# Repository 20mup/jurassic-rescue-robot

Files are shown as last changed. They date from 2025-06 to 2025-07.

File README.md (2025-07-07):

# 🦖 Jurassic Rescue Robot

A semi-autonomous rescue robot developed for the **MREN 303: Mechatronics Design** course at Queen’s University. Designed to traverse a gameboard, press a gate-opening button autonomously, and manually retrieve a "Ken" doll while clearing the "dinosaur" figures under strict hardware constraints.

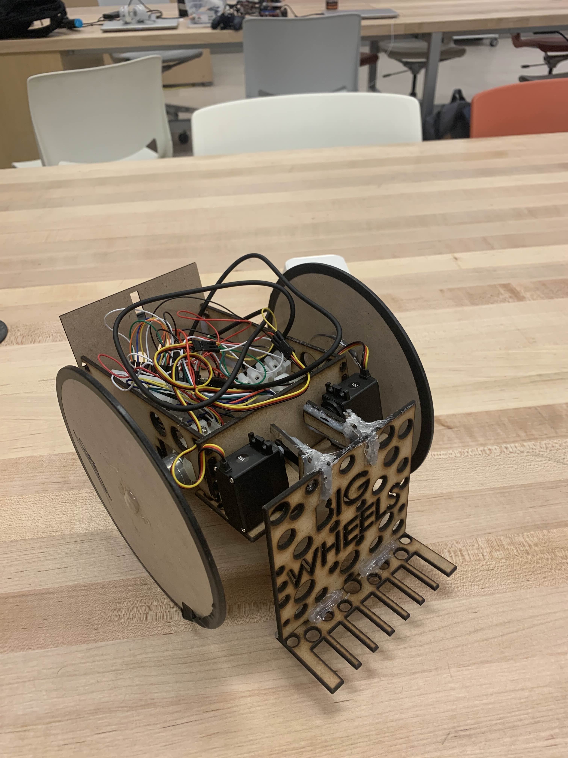
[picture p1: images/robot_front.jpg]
Robot Front View


---

## 🏆 Awards

> 🥇 **People’s Choice Award** – Voted best design and execution by peers and faculty.

---

## 📸 Gallery

| Front | Side | Back |
|---|---|---|
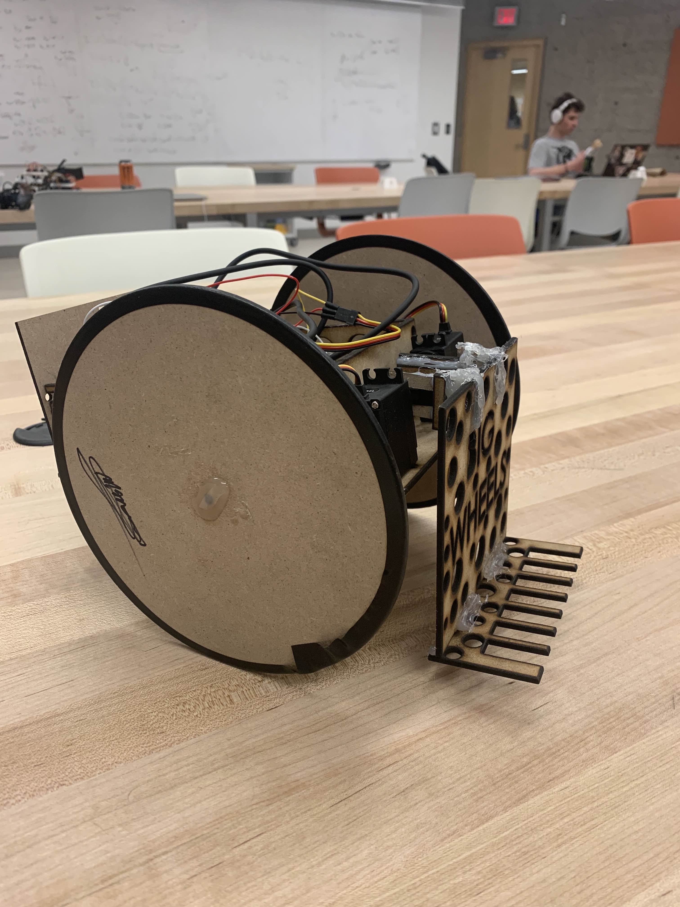
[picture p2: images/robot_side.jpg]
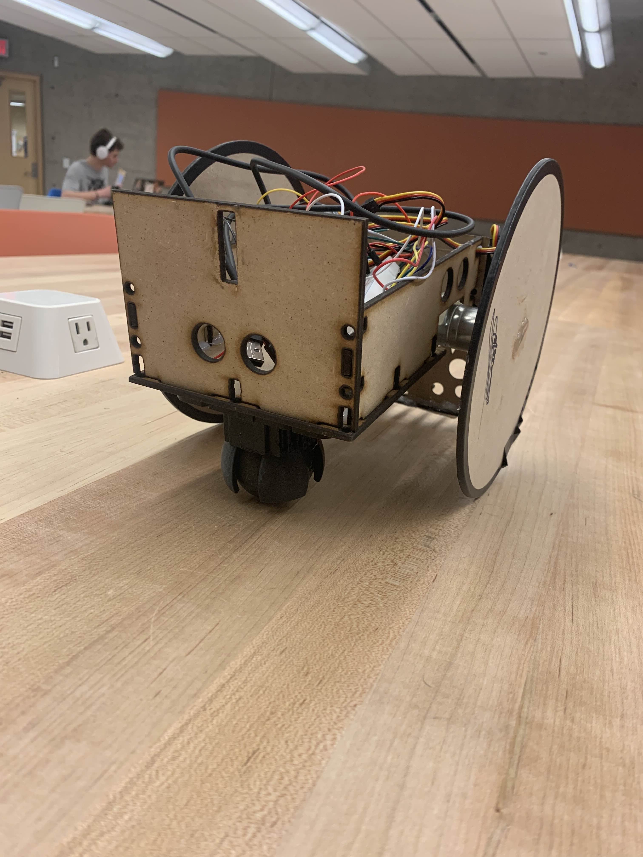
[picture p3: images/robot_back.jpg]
|  |  |  |

| Award | Circuit | Gameboard |
|---|---|---|
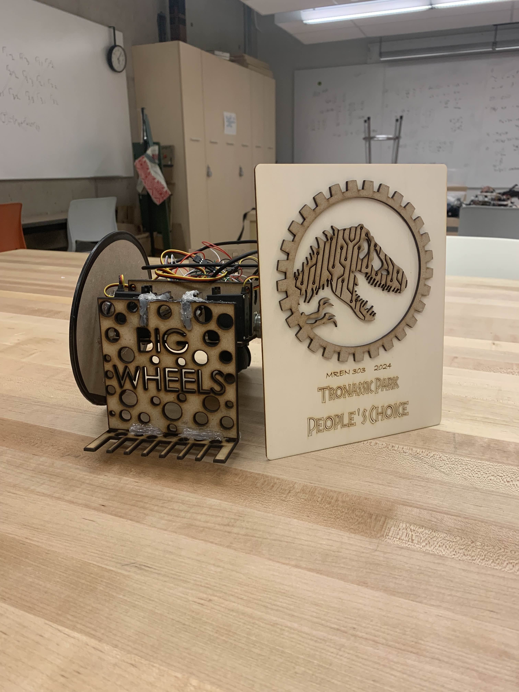
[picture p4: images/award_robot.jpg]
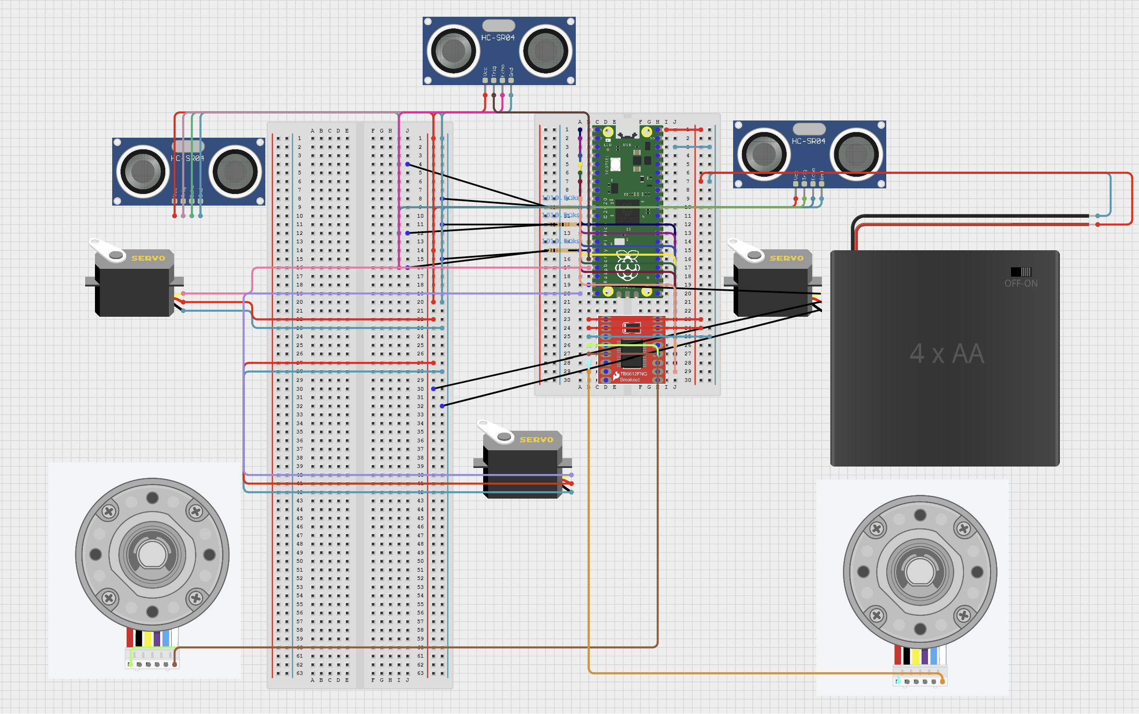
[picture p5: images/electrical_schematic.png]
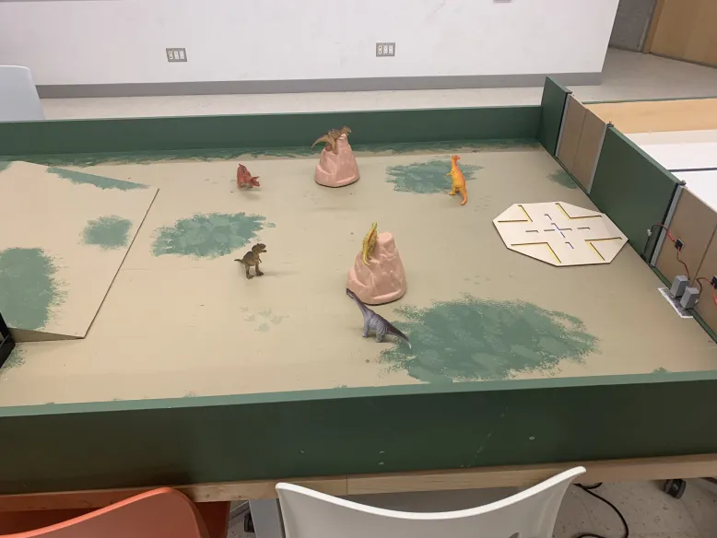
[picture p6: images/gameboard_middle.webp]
|  |  |  |

---

## 🚀 Project Overview

Built for Queen’s University’s **Tronassic Park Competition**, this robot combined autonomous and manual control to complete a two-phase mission:
- **Phase 1:** Autonomously press a button to open a gate.
- **Phase 2:** Switch to joystick control to retrieve a toy figure from a pit.

---

## 🧩 Problem / 💡 Solution

**Problem:** Navigate an uneven gameboard, press a button accurately, and retrieve an object — all using only 3 servo motors and custom electronics.  
**Solution:** A compact, dual-mode robot using ultrasonic alignment and DC motor encoders, with a front clamp to lift the target figure like a forklift.

---

## ✨ Key Features

- Autonomous navigation using ultrasonic sensors
- Manual control via joystick (Arduino + Pico W)
- Closed-loop motor feedback with DC encoders
- Custom 3D-printed chassis and laser-cut wheels
- Integrated power management (voltage dividers)
- Emergency override via controller

---

## 💻 Tech Stack

| Area | Tools / Tech |
|---|---|
| Microcontroller | Raspberry Pi Pico W, Arduino |
| Programming | MicroPython, Arduino C++ |
| CAD & Fabrication | SolidWorks, laser cutting, 3D printing |
| Communication | USB Serial, Joystick |

---

## 📁 Project Structure

```bash
JurassicRescueRobot/
├── code/                   # MicroPython + Arduino scripts
├── design/                 # CAD files (.SLDPRT, .STL, .DXF)
├── images/                 # Robot photos & schematics
├── docs/                   # Engineering case study & final report
└── README.md
```

---

## 👥 Team

- **Mousa Pirzada** – Lead Programmer: Pico W scripting, encoder feedback, integration.
- **Kaitlyn Johnston** – Electrical + Mechanical: Circuit design, CAD, fabrication.

---

## 📖 Learn More

- [📂 CAD Files & Build Details](https://github.com/20mup/JurassicRescueRobot/tree/main/design)
- [📄 Engineering Case Study](docs/jurassic-rescue-case-study.md)

---

> _Built with gears, wires, and the spirit of Jurassic Park._ 🦕

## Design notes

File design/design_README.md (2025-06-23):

# 🧩 Design Files — Jurassic Rescue Robot

This folder contains all mechanical design files used for laser cutting, 3D printing, and assembling the robot chassis and modules.

---

## 📐 Files Overview

### 🖨️ 3D Printing
- `Ball_Caster.stl`  
  → 3D model of the rear omni-directional caster. Positioned at the rear center of the chassis to support two-wheel drive turning.

---

### 🧱 SolidWorks CAD Parts (`.SLDPRT`)
- `Front.SLDPRT`  
  → Front chassis wall for structural support and mounting  
- `back.SLDPRT`  
  → Rear panel of the chassis  
- `base.SLDPRT`  
  → Bottom panel of the robot where all components were mounted  
- `sides.SLDPRT`  
  → Side walls, included for structure and possible mounting of sensors or decorations

> All parts were designed with tight tolerances for laser cutting and easy alignment.

---

### ✂️ Laser Cutting
- `WheelWithDimensions.dxf`  
  → Cut-ready DXF file for the robot’s wheel design. Includes dimensioning to ensure fit on the motor shaft and smooth rotation. Final version fixed tolerance issues seen in cardboard prototype.

---

## 🛠️ Assembly Notes

- All chassis panels were laser cut from wood/acrylic sheets
- Ball caster was 3D printed and press-fitted into the chassis
- Fitment tolerances were fine-tuned after testing in earlier rounds
- Final design minimized unnecessary weight and maximized stability for both manual and autonomous modes

---

## 🧪 Design Iteration Summary

- 📦 Round 1: Initial designs built with cardboard for fit testing  
- ✏️ Round 2–3: CAD models refined using SolidWorks  
- 🖨️ Round 4–5: Final parts laser cut or 3D printed and tested on the gameboard

---

## 👨‍💻 Contributors

- Mousa Pirzada — CAD Design + Fitment Testing  
- Kaitlyn Johnston — Laser Cut Prep + Fabrication

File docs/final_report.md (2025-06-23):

# 📘 Final Report — Jurassic Rescue Robot

**Course**: MREN 303 — Mechatronics and Robotics Design  
**Team**: Mousa Pirzada & Kaitlyn Johnston
**Award**: 🏆 People's Choice Award – Tronassic Park Robotics Challenge (2024)

---

## 🧠 Project Overview

This project challenged teams to build a robot for a Jurassic Park-themed gameboard. The robot's main tasks:
- Autonomously press a button to open a gate
- Manually rescue a doll (Ken) and deliver it to the helipad
- Bonus: corral dinosaur figures into a cage

Our final robot featured a dual mechanism: a **plow** for scooping and a **vertical clamp** for secure object retrieval, optimized for both speed and precision.

---

## 🔁 Design Round Reflections

### 🔹 Round 1: Concept Selection & Risk Assessment
- Brainstormed 5 mechanisms: plow, horizontal claw, frying pan, crane claw, and plow + vertical clamp
- Selected **Plow + Vertical Clamp** for versatility and simplicity
- Created a detailed FRDPARRC table and safety plan
- Prototyped designs using cardboard and began safety assessments

---

### 🔹 Round 2: Subsystem Development
- Learned to interface with motor drivers, servos, and ultrasonic sensors
- Measured all gameboard components and Ken
- Developed CAD for claw and chassis
- Built test circuits and began 3D printing wheels and laser cutting parts
- Identified tolerances and weaknesses in early prototypes

---

### 🔹 Round 3: Integration Begins
- Created full electrical schematic + power budget
- Wired encoders and developed PID motor control
- Combined all control code modules
- Integrated joystick/gamepad for manual control
- Assembled first physical robot with working electronics

---

### 🔹 Round 4: Autonomous Mode + Chassis Iteration
- Built new laser-cut + 3D printed chassis with better part tolerances
- Integrated all sensors and battery monitoring
- Switched between manual and autonomous modes using joystick control
- Tested robot on real gameboard; practiced navigation
- Refined claw design for reliable grip

---

### 🔹 Round 5: Final Testing & Competition Prep
- Implemented autonomous mode logic using ultrasonic sensors
- Merged all final code into single working build
- Final chassis iteration completed with tight motor fits
- Focused on closed-loop feedback performance and autonomous consistency
- Developed presentation and uploaded files for cutting

---

## 📊 Key Takeaways

- Learned how to use **Raspberry Pi Pico**, PWM, encoders, PID control, and servo logic
- Practiced **rapid iteration**, from cardboard to final laser/3D printed modules
- Used **Scrum** and weekly retrospectives to adjust goals, handle setbacks, and improve team dynamics
- Applied **sustainable design** principles by minimizing materials and optimizing energy use
- Balanced **precision + simplicity** under motor, size, and component constraints

---

## 💬 Team Reflections

- Team communication was consistent but could benefit from more mid-week meetings
- We grew stronger in emphasizing high standards, especially near the end
- Our confidence improved through troubleshooting and iteration
- Key lesson: always build in slack time for 3D printing, testing, and fallback planning

---

## 📎 Supporting Files

- 📐 Laser cut drawings (.DXF)
- 🧠 Control code (MicroPython)
- 🖼️ Photos: final robot, cardboard prototypes, award
- 🗂️ CAD files (SolidWorks)

---

## 🫂 Acknowledgements

Thanks to our instructors, lab staff, and peers who provided feedback and help throughout. This project was a powerful hands-on experience in robotics and teamwork.

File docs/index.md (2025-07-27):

# 🦖 Jurassic Rescue Robot — Case Study

> **A semester-long, fully custom robotics build for Queen’s University's MREN 303 design course.**  
> From concept to competition, this case study covers the technical process, design pivots, personal challenges, and final results.

---

## 🎯 Project Context

This project was the central component of **MREN 303: Mechatronics Design** at Queen’s University, a course focused on developing technical design skills through hands-on team projects. The in-class theory was minimal — most of the learning occurred during the development of a functional, competition-ready robot.

Our challenge:  
Design a **semi-autonomous robot** capable of navigating a Jurassic Park-themed board, pressing a gate-opening button autonomously, and retrieving a "dinosaur" figurine manually — all under strict mechanical, electrical, and coding constraints.

---

## 🧠 Initial Strategy

We started with the idea of a **ramp-plus-clamp** rescue mechanism. The concept was to guide the robot onto a sloped ramp, align with the object, and use a servo-powered claw to lift it.

However, this design quickly introduced problems:
- Too many degrees of freedom for the servos
- Increased instability due to shifting weight
- Complex alignment during pickup

After evaluating the trade-offs, we pivoted to a **forklift-style ramp**: a flat platform that could wedge under the object and lift it vertically — fewer moving parts, more reliable.

---

## 🛠️ My Role

As the **lead programmer**, I handled:
- **Raspberry Pi Pico W scripting**
- **Encoder integration and closed-loop motor feedback**
- **Autonomous navigation using ultrasonic sensors**
- **Manual joystick control tuning**
- **Electrical debugging and system integration**

I also participated in weekly Scrum planning, task breakdowns, and integration sessions with my teammate Kaitlyn.

---

## ⚠️ Final Week Setback

Two weeks before our final presentation and test drive, **my laptop’s hard drive failed**. I lost everything — code, notes, CAD references. With the final milestone fast approaching, I had no choice but to **rebuild my entire contribution from scratch**.

For two weeks, I worked non-stop:
- Rewriting all control logic from memory
- Re-integrating encoder feedback and motor control
- Running late-night hardware tests
- Debugging under pressure with no time to spare

Despite this major setback, we managed to finish and deliver the project on time — fully functional and ready for demo day.

---

## 📏 Constraints & Challenges

- **3 servo motor limit**
- **Raspberry Pi Pico W + Arduino hybrid**
- No pre-made chassis or wheels — all laser cut or 3D printed
- Physical button pressing required precision
- No external debugging tools beyond onboard prints

---

## 🧪 Testing Process

Testing was iterative and often frustrating:
- Ultrasonic sensor alignment required ideal angle calibration
- Closed-loop motor control needed constant PID retuning
- Button pressing demanded perfect perpendicular alignment
- Battery fluctuations affected consistency

We learned the importance of **physical tolerances**, **debounce logic**, and real-world testing beyond simulations.

---

## 🏁 Results

The robot successfully:
- Navigated the board autonomously to press the gate button
- Transitioned into manual mode for precision pickup
- Completed the full task sequence within the competition time

We were honored to win the:

> 🥇 **People’s Choice Award**  
> _Voted best robot design and execution by peers and faculty._

---

## 🧠 Takeaways

- Don’t overcomplicate early designs — iterate based on simplicity first
- CAD precision is just as important as code
- Documentation + backups are life-saving
- Clear division of roles made collaboration smooth
- Real innovation happens under constraints

---

## 👥 Team Members

- **Mousa Pirzada** — Lead Programming, System Integration, Motor Control
- **Kaitlyn Johnston** — CAD Design, Circuit Assembly, Fabrication

---

## 📎 Related Links

- [🔗 GitHub Repository](https://github.com/20mup/Jurassic-Rescue-Robot)
- [📂 CAD & Files](https://github.com/20mup/Jurassic-Rescue-Robot/design)
- [🏆 View the Main Portfolio Page](/projects/jurassic-rescue-robot)

---

> _Built with gears, wires, and the spirit of Jurassic Park._ 🦕

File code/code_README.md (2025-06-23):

# 🧠 Code Overview — Jurassic Rescue Robot

This folder contains the core codebase for our autonomous + manual control robot built with the Raspberry Pi Pico.

---

## 📂 Files

### `pico_main_control.ino`
- ⚙️ Arduino-style program uploaded to the Raspberry Pi Pico
- Receives joystick commands via WiFi (UDP)
- Controls:
  - Motors (via H-bridge)
  - Servos for claw/lifting mechanism
  - Ultrasonic sensor for autonomous navigation
  - Battery monitoring
- Includes logic for closed-loop feedback using motor encoders + PID control

---

### `gamepad_input_udp.py`
- 🕹️ Python script that runs on the host PC
- Reads gamepad input using the `inputs` package
- Sends encoded UDP packets to the robot’s IP address
- Supports:
  - Joystick X/Y axes
  - All buttons and triggers
  - Mode switching (manual vs autonomous)

> 🔧 Ensure your gamepad is in **XInput mode** and your PC is on the same WiFi network as the Pico.

---

## 🛠️ Setup Notes

- The Pico and the host machine must be connected to the **same network**
- The IP address in `gamepad_input_udp.py` must match the Pico’s assigned address
- Use `Thonny` or Arduino IDE to upload `.ino` code to the Pico
- Install Python dependencies:
  ```bash
  pip install inputs
  ```

---

## 🔄 Data Flow

```
Gamepad → PC (Python) → UDP → Raspberry Pi Pico → Motors / Servos / Sensors
```

---

## 📎 Dependencies

- Python 3.x
- [`inputs`](https://pypi.org/project/inputs/) (for reading gamepad input)
- Arduino/Thonny IDE for Pico code upload

---

## 👨‍💻 Authors

- Mousa Pirzada — Python + Embedded Logic
- Kaitlyn — Electronics + Hardware Integration

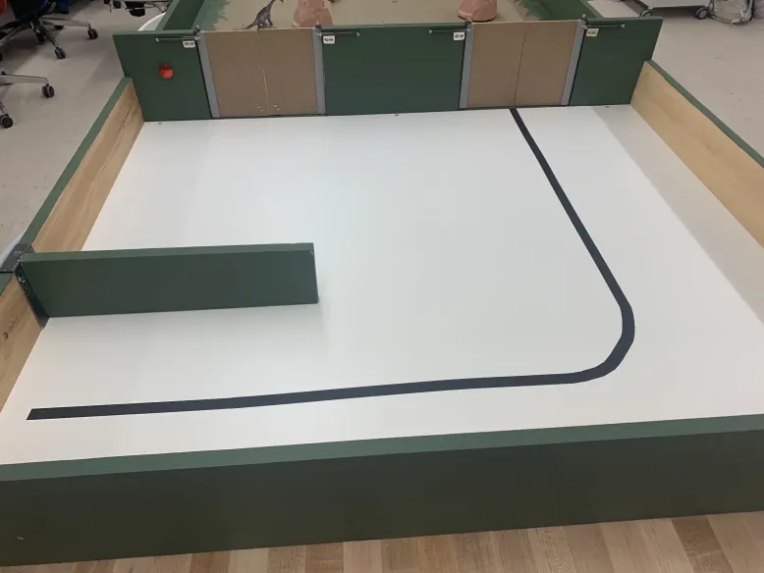
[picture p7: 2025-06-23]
images/gameboard_start.webp

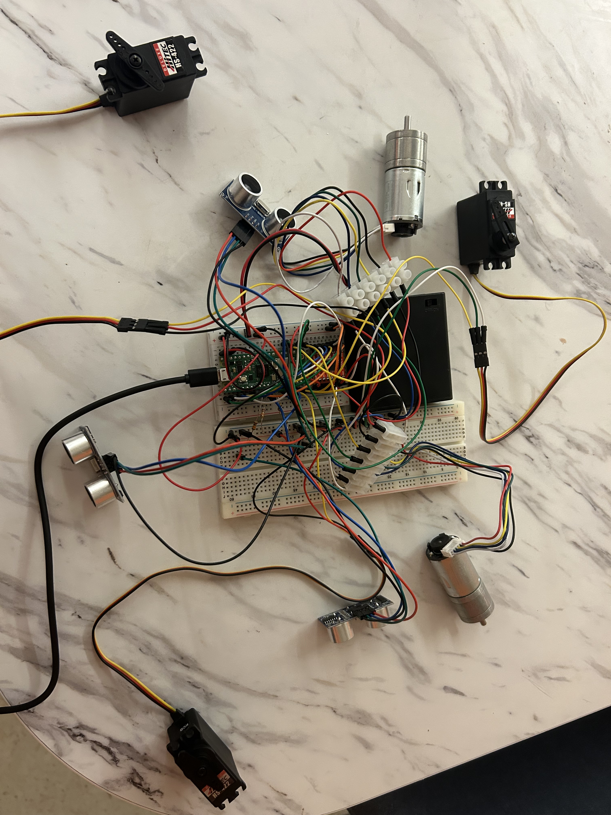
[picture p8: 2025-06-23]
images/Electrical_Circuit.jpg

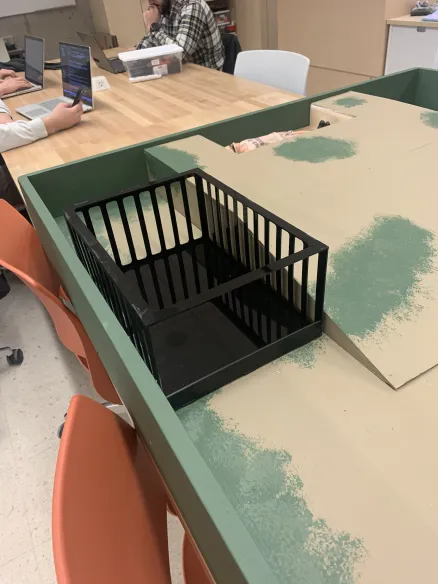
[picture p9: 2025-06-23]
images/gameboard_end.webp

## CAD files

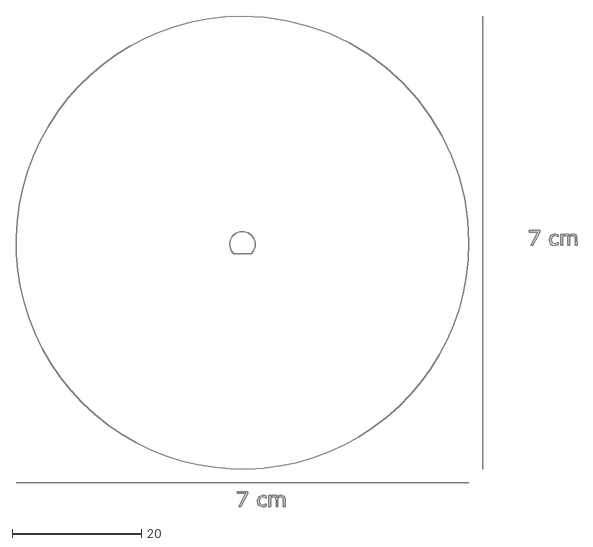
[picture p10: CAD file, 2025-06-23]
design/WheelWithDimensions.dxf
86.7 x 75.8

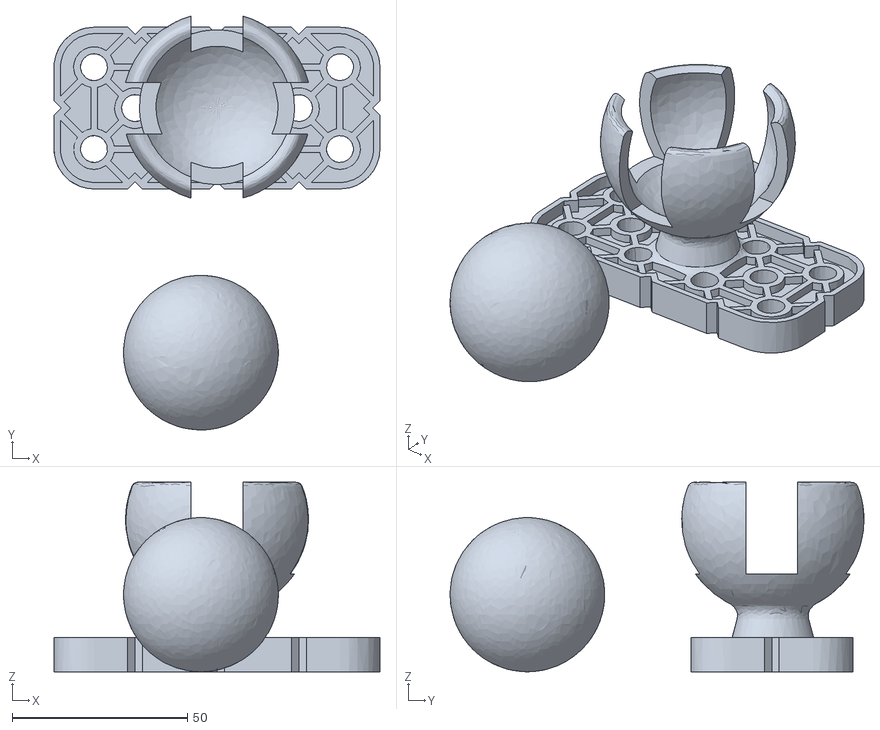
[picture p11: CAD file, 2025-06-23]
design/Ball_Caster.stl
93.0 x 118.1 x 54.1

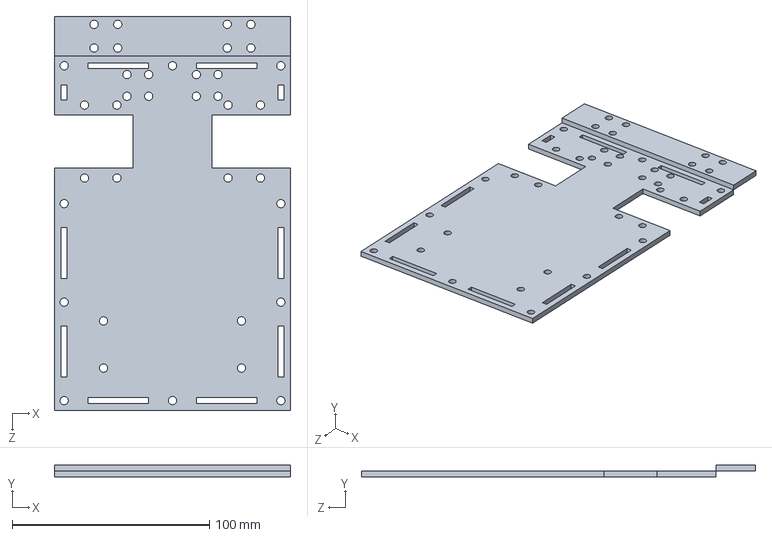
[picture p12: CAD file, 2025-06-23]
design/base.SLDPRT
120.0 x 6.00 x 200.0 mm

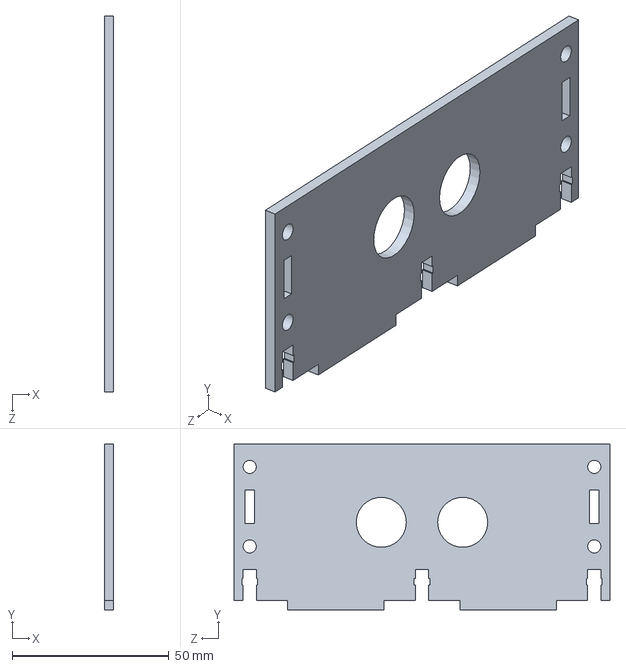
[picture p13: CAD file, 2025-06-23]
design/Front.SLDPRT
3.00 x 53.0 x 120.0 mm

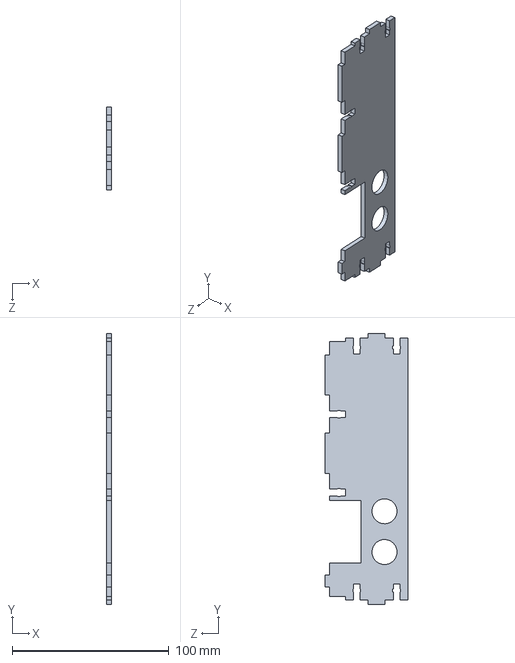
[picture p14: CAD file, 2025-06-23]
design/sides.SLDPRT
3.00 x 173.0 x 53.0 mm

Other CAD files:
design/back.SLDPRT

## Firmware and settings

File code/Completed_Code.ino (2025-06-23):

// MREN 303 Pico W Wifi Gamepad Read
// Written For MREN 303 

#include <WiFi.h>
#include <WiFiUdp.h>
#include <Servo.h>
#include <Arduino.h>

Servo myservo; 
Servo myservo2; 
Servo myservo3; 



#ifndef STASSID
#define STASSID "MREN303_wifi"
#define STAPSK "MREN@303p1"
#endif

unsigned int localPort = 8888;  // local port to listen on

// buffers for receiving and sending data
char packetBuffer[UDP_TX_PACKET_MAX_SIZE + 1];  // buffer to hold incoming packet,
char ReplyBuffer[22] = "acknowledged\r\n";        // a string to send back
// char Arrays to match commands from gamepad 
char stringA[17] =    "A Button Press";
char stringB[17] =    "B Button Press";
char stringY[17] =    "Y Button Press";
char stringX[17] =    "X Button Press";
char stringLB[17] =   "LB Button Press";
char stringRB[17] =   "RB Button Press";
char stringLS[17] =   "L Stick Press";
char stringRS[17] =   "R Stick Press";
char stringBack[17]=  "Back Press";
char stringStart[17]= "Start Press";
char stringUp[17] =   "Up Dpad Press";
char stringDown[17] = "Down Dpad Press";
char stringLeft[17] = "Left Dpad Press";
char stringRight[17]= "Right Dpad Press";
char stringLX[17] =   "L Stick X Value ";
char stringLY[17] =   "L Stick Y Value ";
char stringRX[17] =   "R Stick X Value ";
char stringRY[17] =   "R Stick Y Value ";
char stringLT[17] =   "L Trigger Value ";
char stringRT[17] =   "R Trigger Value ";

int valueLx = 0;
int valueLy = 0;
int valueRx = 0;
int valueRy = 0;
int valueLt = 0;
int valueRt = 0; 
int batteryLevel = 0;
int threshold = 100;
int threshold2 = -100;


bool ledOn = false;
bool pollBattery = false;
bool LeftMotorOn = false;
bool RightMotorOn = false;
bool LeftMotorOff = false;
bool RightMotorOff = false;
bool LeftMotorBack = false;
bool RightMotorBack = false;

//game modes
const int IDLE_MODE = 0;
const int AUTO_MODE = 1;
const int MANUAL_MODE = 2;
int current_mode = IDLE_MODE; // Variable to store the current mode. Starts in idle mode

unsigned long startTime = 0;  // Variable to store the start time
unsigned long currentTime = 0; // Variable to store the current time

WiFiUDP Udp;

// Define motor driver pins according to your hookup
const int PWMA = 19; // PWM control for motor speed, connect to PWM-enabled pin on Pico
const int AIN1 = 17; // Direction pin 1 for motor A, connect to a GPIO on Pico
const int AIN2 = 18; // Direction pin 2 for motor A, connect to a GPIO on Pico
const int STBY = 16; // Standby pin, connect to a GPIO on Pico
const int PWMA2 = 22; // PWM control for motor speed, connect to PWM-enabled pin on Pico
const int AIN12 = 20; // Direction pin 1 for motor A, connect to a GPIO on Pico
const int AIN22 = 21; // Direction pin 2 for motor A, connect to a GPIO on Pico
int counter = 0;

// defines pins numbers
const int trigPin = 3;
const int echoPin = 2;
const int trigPin1 = 1;
const int echoPin1 = 0;
const int trigPin2 = 5;
const int echoPin2 = 4;

// defines variables
long duration;
int distance;
long duration1;
int distance1;
long duration2;
int distance2;



void setup() { //This handles network function and runs on core 1
  Serial.begin(115200);
  WiFi.begin(STASSID, STAPSK);
  while (WiFi.status() != WL_CONNECTED) {
    Serial.print('.');
    delay(500);
  }
  Serial.print("Connected! IP address: ");
  Serial.println(WiFi.localIP());
  Serial.printf("UDP server on port %d\n", localPort);
  Udp.begin(localPort);

}
void setup1(){ //This handles all inputs and outputs and runs on core 2
  
  pinMode(LED_BUILTIN, OUTPUT);
  digitalWrite(LED_BUILTIN,0);
  myservo.attach(15);
  myservo2.attach(14);
  myservo3.attach(13);
  analogReadResolution(12); // 12 bit resolution = 0 - 4096 (2^12)

    // Set motor driver pins as outputs
  pinMode(PWMA, OUTPUT);
  pinMode(AIN1, OUTPUT);
  pinMode(AIN2, OUTPUT);
  pinMode(STBY, OUTPUT);
  pinMode(PWMA2, OUTPUT);
  pinMode(AIN12, OUTPUT);
  pinMode(AIN22, OUTPUT);

  pinMode(trigPin, OUTPUT); // Sets the trigPin as an Output
  pinMode(echoPin, INPUT); // Sets the echoPin as an Input
  pinMode(trigPin1, OUTPUT); // Sets the trigPin as an Output
  pinMode(echoPin1, INPUT); // Sets the echoPin as an Input
  pinMode(trigPin2, OUTPUT); // Sets the trigPin as an Output
  pinMode(echoPin2, INPUT); // Sets the echoPin as an Input
  
  // Pull standby pin high to enable the motor driver
  digitalWrite(STBY, HIGH);

}

void loop() { //This loop executes on Core 1 of the Pico, handles networking and recieves commands
  // if there's data available, read a packet
  int packetSize = Udp.parsePacket();
  if (packetSize) {
    Serial.printf("Received packet of size %d from %s:%d\n    (to %s:%d)\n", packetSize, Udp.remoteIP().toString().c_str(), Udp.remotePort(), Udp.destinationIP().toString().c_str(), Udp.localPort());

    // read the packet into packetBufffer
    int n = Udp.read(packetBuffer, UDP_TX_PACKET_MAX_SIZE);
    packetBuffer[n] = 0;

    char comparisonString[17] = "";
    char valueString[5] = "";

    for (int i=0; i<16 ; i++){
      comparisonString[i]=packetBuffer[i];
    }
    comparisonString[16] = 0;
    
    Serial.println("Comp String:");
    Serial.println(comparisonString);

    if (strcmp(comparisonString,stringA) == 0){
      Serial.println("Setting mode to idle");//this line may be removed for final version
      current_mode = IDLE_MODE; // Change to idle mode
    }   
    if (strcmp(comparisonString,stringB) == 0){
      Serial.println("Turning Off LED");
      ledOn = false;
    }
    if (strcmp(comparisonString,stringY) == 0){
      if (current_mode == IDLE_MODE){ // You can only go to auto mode from idle mode
        Serial.println("Setting mode to auto");//this line may be removed for final version
        current_mode = AUTO_MODE; // Change to auto mode
        startTime = millis();  // Start recording the time

      }           
    }
    if (strcmp(comparisonString,stringX) == 0){
      Serial.println("Setting mode to manual");//this line may be removed for final version
      current_mode = MANUAL_MODE; // Change to manual mode
    }
    if (strcmp(comparisonString,stringStart) == 0){
      Serial.println("Polling Battery Level");
      pollBattery = true;
      char pollBatteryMessage[] = "Polling Battery Level"; 
      memcpy(ReplyBuffer,pollBatteryMessage,22);
    }
    if (strcmp(comparisonString,stringLX) == 0){
      for(int i=16; i<=packetSize ; i++){
        valueString[(i-16)] = packetBuffer[i];}
      valueString[5] = 0;
      valueLx = atoi(valueString);
      Serial.println("LX Value is:");
      Serial.println(valueLx);
      if (valueLx > threshold){
      LeftMotorBack = true;
      RightMotorOn = true;
    }
      else if (valueLx <threshold2){
      LeftMotorOn = true;
      RightMotorBack = true;
    }
      else if (threshold2<valueLx<threshold){
      LeftMotorOff = true;
      RightMotorOff = true;
    }
    }
    if (strcmp(comparisonString,stringLY) == 0){
      for(int i=16; i<=packetSize ; i++){
        valueString[(i-16)] = packetBuffer[i];}
      valueString[5] = 0;
      valueLy = atoi(valueString);
      Serial.println("LY Value is:");
      Serial.println(valueLy);
      if (valueLy > threshold){
      LeftMotorBack = true;
      RightMotorBack = true;
    }
      else if (valueLy <threshold2){
      LeftMotorOn = true;
      RightMotorOn = true;
    }
      else if (threshold2<valueLy<threshold){
      LeftMotorOff = true;
      RightMotorOff = true;
    }
    }
    if (strcmp(comparisonString,stringRX) == 0){
      for(int i=16; i<=packetSize ; i++){
        valueString[(i-16)] = packetBuffer[i];}
      valueString[5] = 0;
      valueRx = atoi(valueString);
      Serial.println("RX Value is:");
      Serial.println(valueRx);
    }
    if (strcmp(comparisonString,stringRY) == 0){
      for(int i=16; i<=packetSize ; i++){
        valueString[(i-16)] = packetBuffer[i];}
      valueString[5] = 0;
      valueRy = atoi(valueString);
      Serial.println("RY Value is:");
      Serial.println(valueRy);
    }
    if (strcmp(comparisonString,stringRT) == 0){
      for(int i=16; i<=packetSize ; i++){
        valueString[(i-16)] = packetBuffer[i];}
      valueString[5] = 0;
      valueRt = atoi(valueString);
      Serial.println("RT Value is:");
      Serial.println(valueRt);
    }
    if (strcmp(comparisonString,stringLT) == 0){
      for(int i=16; i<=packetSize ; i++){
        valueString[(i-16)] = packetBuffer[i];}
      valueString[5] = 0;
      valueLt = atoi(valueString);
      Serial.println("LT Value is:");
      Serial.println(valueLt);
    }
    

    // send a reply, to the IP address and port that sent us the packet we received
    if(pollBattery){ //Wait for battery read to reply 
      delay(20);
    }
    Udp.beginPacket(Udp.remoteIP(), Udp.remotePort());
    Udp.write(ReplyBuffer);
    Udp.endPacket();
  }
}

void loop1(){ //This Runs on Core 2 and performs all inputs and outputs

  if(ledOn){
    digitalWrite(LED_BUILTIN,1);
  }
  else{
    digitalWrite(LED_BUILTIN,0);
  }
  int servoPos = map(valueRx,-255,255,0,180);
  myservo.write(servoPos);
  int servoPos2 = map(valueRx,255,-255,0,180);
  myservo2.write(servoPos2);
  if(pollBattery){
    readBattery();
    pollBattery = false;
  }
studentCode(current_mode);

currentTime = millis();

// After spending more than 30 s in auto mode:
if ((current_mode == AUTO_MODE) && (currentTime - startTime) >= 30000) {
  Serial.println("TIME OUT: changing to manual mode");//this line may be removed for final version
  current_mode = MANUAL_MODE; // Change to manual mode
  }
}

void readBattery(){
  int voltage = analogRead(A0);
  Serial.println("Voltage reading is:");
  Serial.println(voltage);
  if (voltage < 200) {
    Serial.println("Battery Not Connected");
  }
  else{
    batteryLevel = map(voltage,2482,3475,0,100);
    char batteryMessage[] = "Battery Level is: %d %";
    sprintf(ReplyBuffer,batteryMessage,batteryLevel);
    Serial.println("Battery Level is :");
    Serial.print(batteryLevel); 
    Serial.print("% \n");  
  }
}

void LeftMotorForward(){
  digitalWrite(AIN1, HIGH);
  digitalWrite(AIN2, LOW);
  analogWrite(PWMA, 128); // 50% duty cycle for speed
}

void RightMotorForward(){
  digitalWrite(AIN12, HIGH);
  digitalWrite(AIN22, LOW);
  analogWrite(PWMA2, 128); // 50% duty cycle for speed
}

void LeftMotorStop(){
  digitalWrite(AIN1, LOW);
  digitalWrite(AIN2, LOW);
  analogWrite(PWMA, 0); // Disabling PWM signal
}

void RightMotorStop(){
  digitalWrite(AIN12, LOW);
  digitalWrite(AIN22, LOW);
  analogWrite(PWMA2, 0); // Disabling PWM signal
}

void LeftMotorBackward(){
  digitalWrite(AIN1, LOW);
  digitalWrite(AIN2, HIGH);
  analogWrite(PWMA, 128); // 50% duty cycle for speed
}

void RightMotorBackward(){
  digitalWrite(AIN12, LOW);
  digitalWrite(AIN22, HIGH);
  analogWrite(PWMA2, 128); // 50% duty cycle for speed
}

// YOUR CODING GOES HERE
void studentCode(int current_mode){ 
  if(current_mode == IDLE_MODE){
   //Serial.println("You are in idle mode");//this line may be removed for final version
    digitalWrite(LED_BUILTIN, LOW); // LED is off for idle mode
   // Initialize motors state as off
    digitalWrite(STBY, HIGH);
    digitalWrite(AIN1, LOW);
    digitalWrite(AIN2, LOW);
    digitalWrite(PWMA, HIGH);
    digitalWrite(AIN12, LOW);
    digitalWrite(AIN22, LOW);
    digitalWrite(PWMA2, HIGH);
  }
  else if (current_mode == AUTO_MODE){
    Serial.println("You are in auto mode");
      //forward
      digitalWrite(AIN1, HIGH);
      digitalWrite(AIN2, LOW);
      analogWrite(PWMA, 128); // 50% duty cycle for speed
      digitalWrite(AIN12, HIGH);
      digitalWrite(AIN22, LOW);
      analogWrite(PWMA2, 150); 
      delay(1200); // Run for 1.5 seconds
               // Initialize motors state as off
      digitalWrite(STBY, HIGH);
      digitalWrite(AIN1, LOW);
      digitalWrite(AIN2, LOW);
      digitalWrite(PWMA, HIGH);
      digitalWrite(AIN12, LOW);
      digitalWrite(AIN22, LOW);
      digitalWrite(PWMA2, HIGH);      
      delay(2000); // Run for 2 seconds
      //left
      digitalWrite(AIN1, HIGH);
      digitalWrite(AIN2, LOW);
      analogWrite(PWMA, 128); // 50% duty cycle for speed
      digitalWrite(AIN12, LOW);
      digitalWrite(AIN22, HIGH);
      analogWrite(PWMA2, 128); // 50% duty cycle for speed
      delay(350); //Run for 0.15 seconds
      //forward
      digitalWrite(AIN1, HIGH);
      digitalWrite(AIN2, LOW);
      analogWrite(PWMA, 128); // 50% duty cycle for speed
      digitalWrite(AIN12, HIGH);
      digitalWrite(AIN22, LOW);
      analogWrite(PWMA2, 128); // No PWM signal needed, but keeping it for consistency
      delay(2000); // Run for 1.5 seconds
         // Initialize motors state as off
      digitalWrite(STBY, HIGH);
      digitalWrite(AIN1, LOW);
      digitalWrite(AIN2, LOW);
      digitalWrite(PWMA, HIGH);
      digitalWrite(AIN12, LOW);
      digitalWrite(AIN22, LOW);
      digitalWrite(PWMA2, HIGH);      
      delay(10000);
   }
  else if (current_mode == MANUAL_MODE){
    Serial.println("You are in manual mode");//this line may be removed for final version
    digitalWrite(LED_BUILTIN, HIGH); // LED is on for manual mode
      if(LeftMotorOn){
    LeftMotorForward();
    LeftMotorOn = false;
  }
  if(RightMotorOn){
    RightMotorForward();
    RightMotorOn = false;
  }
  if(LeftMotorBack){
    LeftMotorBackward();
    LeftMotorBack = false;
  }
  if(RightMotorBack){
    RightMotorBackward();
    RightMotorBack = false;
  }
  if(LeftMotorOff){
    LeftMotorStop();
    LeftMotorOff = false;
  }
  if(RightMotorOff){
    RightMotorStop();
    RightMotorOff = false;
  }
  }
  return;
}
